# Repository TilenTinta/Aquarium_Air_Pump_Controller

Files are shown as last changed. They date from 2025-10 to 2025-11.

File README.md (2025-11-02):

# Aquarium_Air_Pump_Controller

Simple electronics for controlling aquarium air pump speed with some additional functions built around the WCH **CH32V003F4U6** MCU

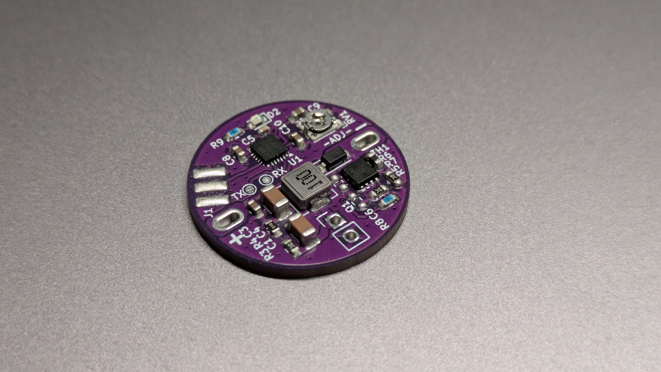
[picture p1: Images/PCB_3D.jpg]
Pump control pcb
  

---

## Table of Contents

- [Overview](#overview)
- [Features](#features)
  - [Hardware](#hardware)
  - [Software](#software)
- [Mounting](#mounting)
- [Flashing Firmware](#flashing-firmware)
- [Working device](#working-device)
  - [Working Principle](#working-principle)
- [Debugging](#debugging)
  - [LED Status Codes](#led-status-codes)

---

## Overview

This controller is a very compact solution for controling aquarium air pump speed. It is meant to be mounted on the back side of cheap chinese pumps that uses DC brushed motors like **PXYP370** and are powered from USB. By adjusting potenciometer on PCB you can tune pump speed and by that the amount of air provided in aquarium/filter. If you want to control this pump from external device like **ESP32** you can connect it over UART pads. This allow you to monitor and control the pump.

---

## Features

### Hardware

- **MCU:** WCH **CH32V003F4U6** with SWIO. 
- **Power:** Directly from 5V - USB.
- **Power regulation:** N-Channel MOSFET AP30N03DF.
- **Adjustment:** Duty cycle with potenciometer
- **Sensors:** Voltage IN, temperature.
- **Indicators/Controls:** Status LED and UART. 

### Software

- **Firmware:** C, developed in **MounRiver Studio IDE**. 
- **Updates:** **Custom bootloader** supports UART firmware updates. 

---

## Mounting

To mount controller on air pump you first need to remove silicon housing from the pump. Desolder both wires and bleed resistor from the motor contacts and clean them. Then solder the wires from USB cable to PCB. Correctly oriented pcb can be then soldered directly on motor contacts.

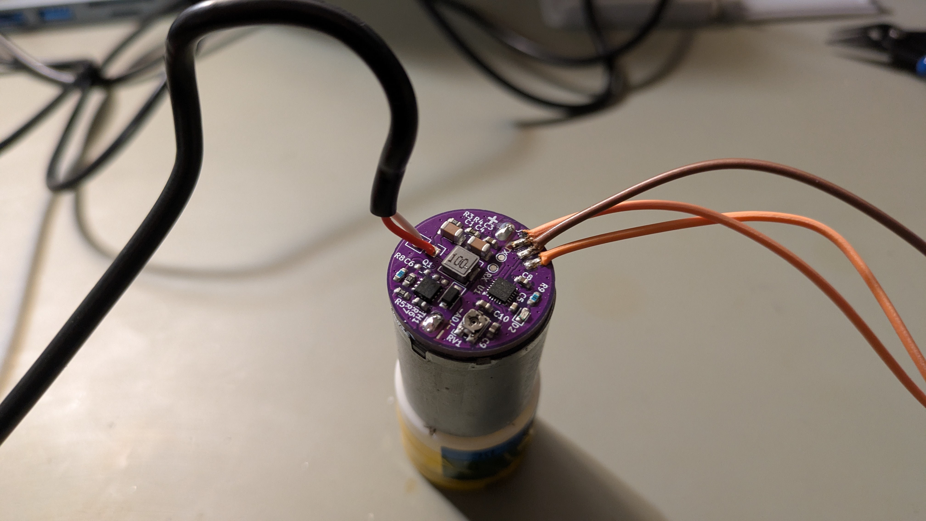
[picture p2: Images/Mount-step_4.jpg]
Pump control full
  

---

## Flashing Firmware

- Open the project in **MounRiver Studio IDE**, compile, and **upload** to the **CH32V003F4U6** MCU. 

> The board also includes a **custom bootloader** for **UART firmware updates** when supported by the desktop toolchain. 

---

## Working device

When USB cable is pluging the controler goes thrue start up routine. After that if everything is okay (input voltage, temperatue) it goes in running mode, otherwise it falls in error state which is indicated with **solid red light**.

### Working Principle

- **Sampling:** The system samples data at 50Hz*. In the first sample, the MCU collects raw measurements. In the next sample, these values are converted into real-world units (V, °C, %). This results in an effective sampling rate of 25Hz for the calculated values.
- **Control Logic:** Based on the collected values, the controller can either trigger an error or set a new duty cycle for the motor based on the potentiometer reading.
- **Error Conditions:**
    - **Over-temperature:** 80°C
    - **Under-voltage:** 3.5V
- **Duty Cycle:** The duty cycle can be set between 10% and 90%. Values below 10% are treated as 0%, and values above 90% are treated as 100%.
    - **Note:** This DC motors require a minimum of 3.0V - 3.5V to start.

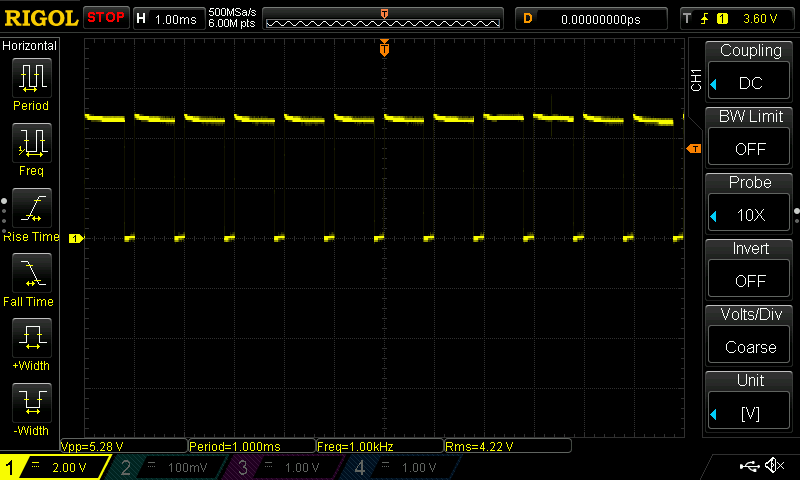
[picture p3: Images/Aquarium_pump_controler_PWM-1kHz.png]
Pump control PWM
 
---

## Debugging

### LED Status Codes  

| LED Pattern | Meaning |
|---|---|
| Blinking **red**  | Device initialization |
| Solid **red** | Device error |

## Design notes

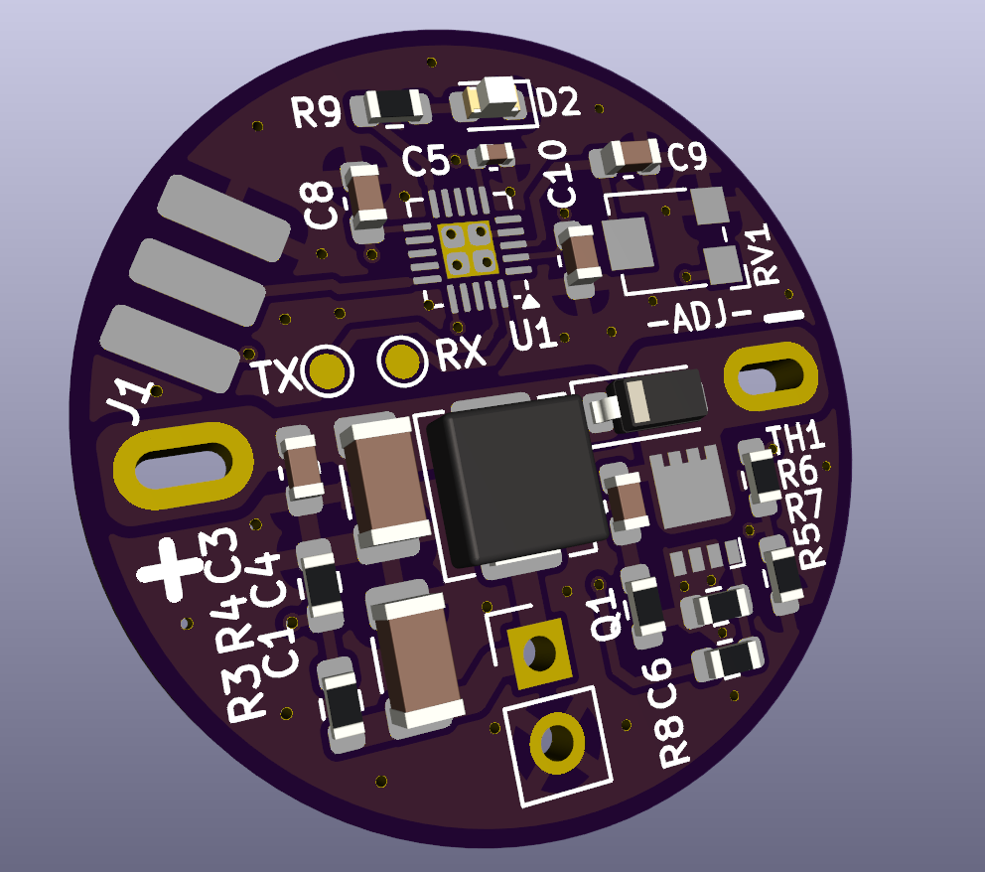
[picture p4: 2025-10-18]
Images/PCB_3D_render.png

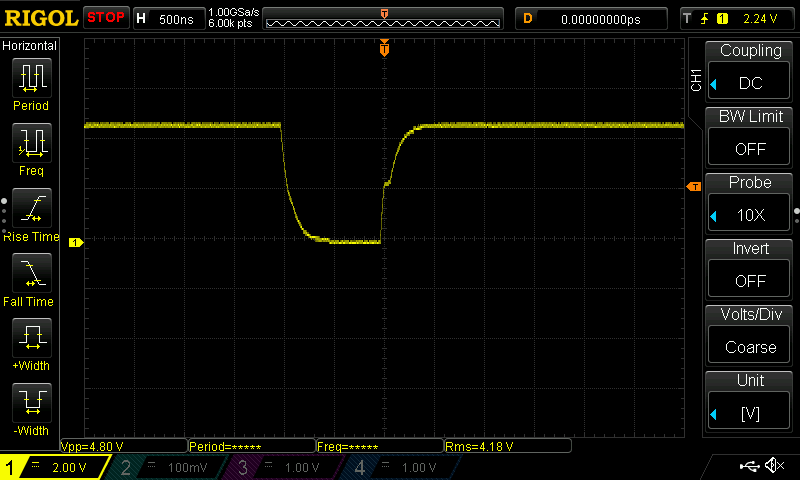
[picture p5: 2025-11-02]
Images/Aquarium_pump_controler_ON-OFF.png

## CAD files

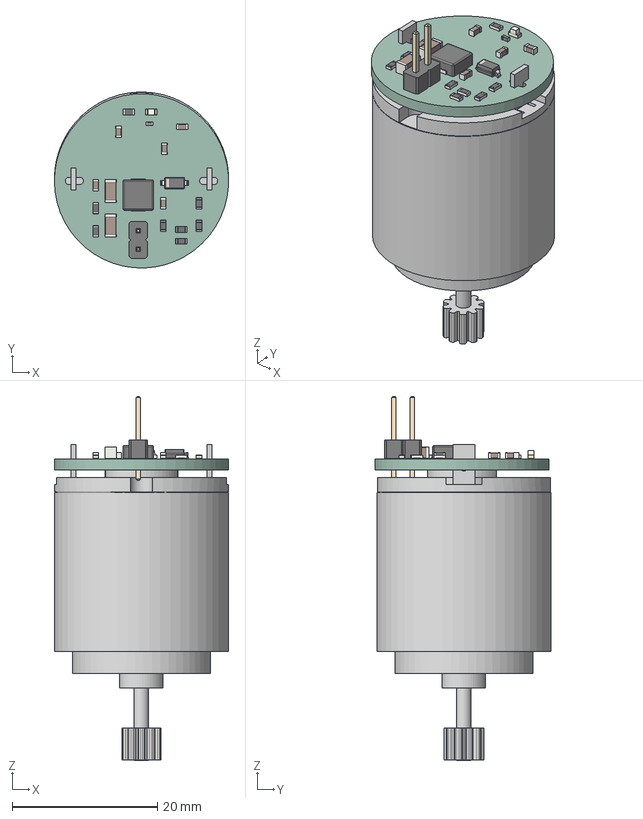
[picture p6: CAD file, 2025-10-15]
3D_Model/Assembly v1.step
24.0 x 24.2 x 50.1 mm
C_0603_1608Metric x 5
R_0603_1608Metric x 8
D_SOD-123
C_0402_1005Metric
C_1206_3216Metric x 2
L_APV_APH0420
PinHeader_1x02_P2.54mm_Vertical
LED_0603_1608Metric
Air_pump_controler_PCB
DC 12 v motor

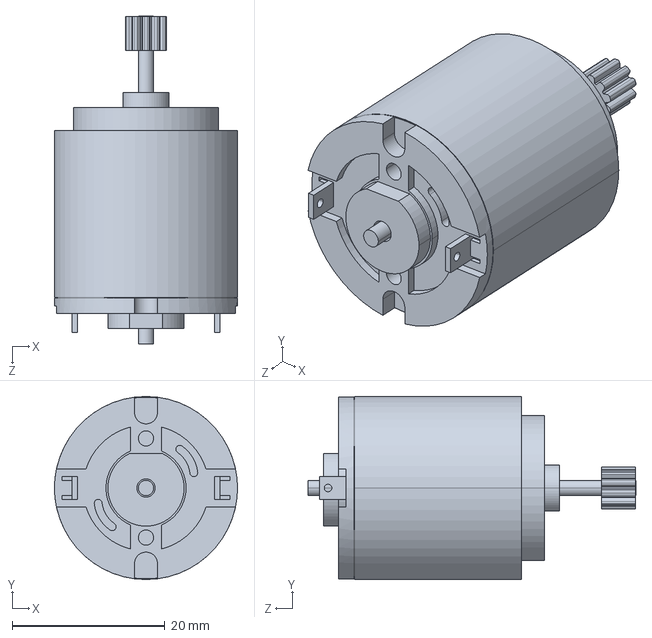
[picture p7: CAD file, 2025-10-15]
3D_Model/DC 12 v motor.STEP
24.0 x 24.0 x 43.0 mm

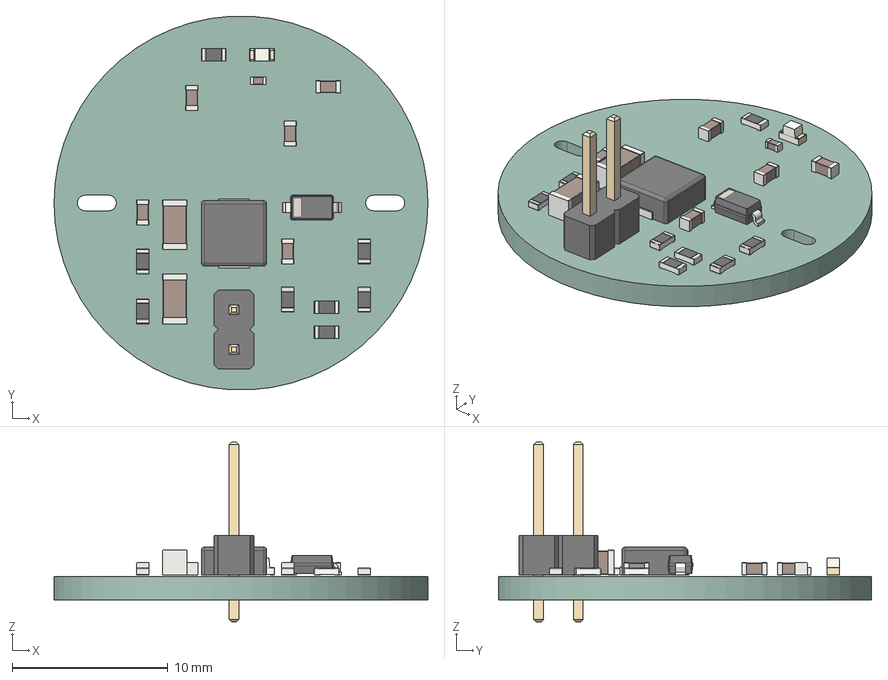
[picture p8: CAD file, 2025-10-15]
3D_Model/Air_pump_controler.step
24.0 x 24.0 x 11.5 mm
C_0603_1608Metric x 5
R_0603_1608Metric x 8
D_SOD-123
C_0402_1005Metric
C_1206_3216Metric x 2
L_APV_APH0420
PinHeader_1x02_P2.54mm_Vertical
LED_0603_1608Metric
Air_pump_controler_PCB

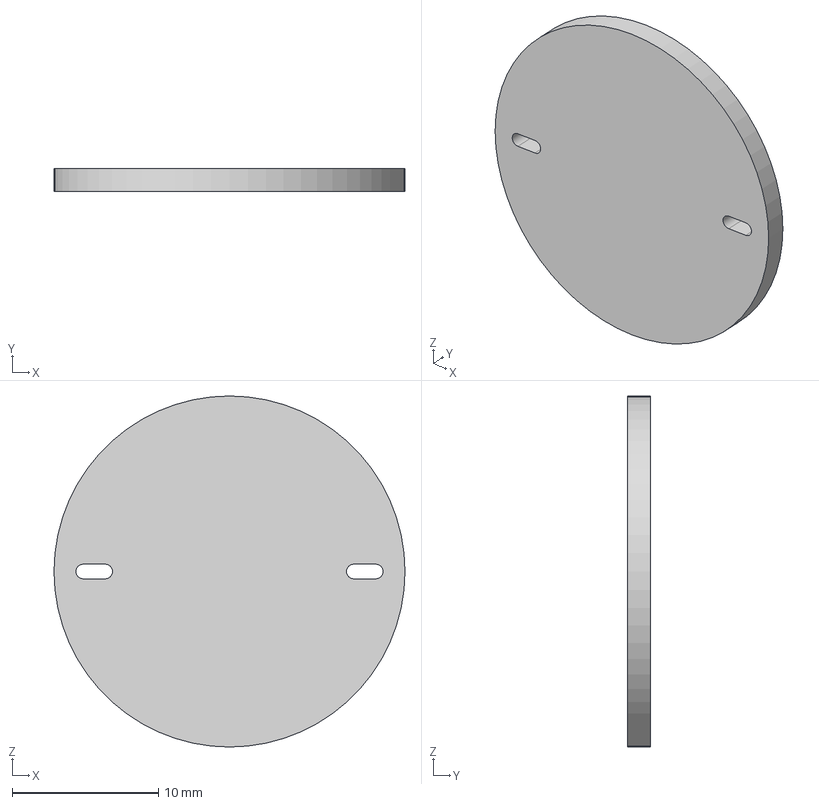
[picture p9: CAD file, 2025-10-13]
3D_Model/PCB_dummy v2.step
24.0 x 1.60 x 24.0 mm

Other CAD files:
3D_Model/PCB_dummy_v2.dxf

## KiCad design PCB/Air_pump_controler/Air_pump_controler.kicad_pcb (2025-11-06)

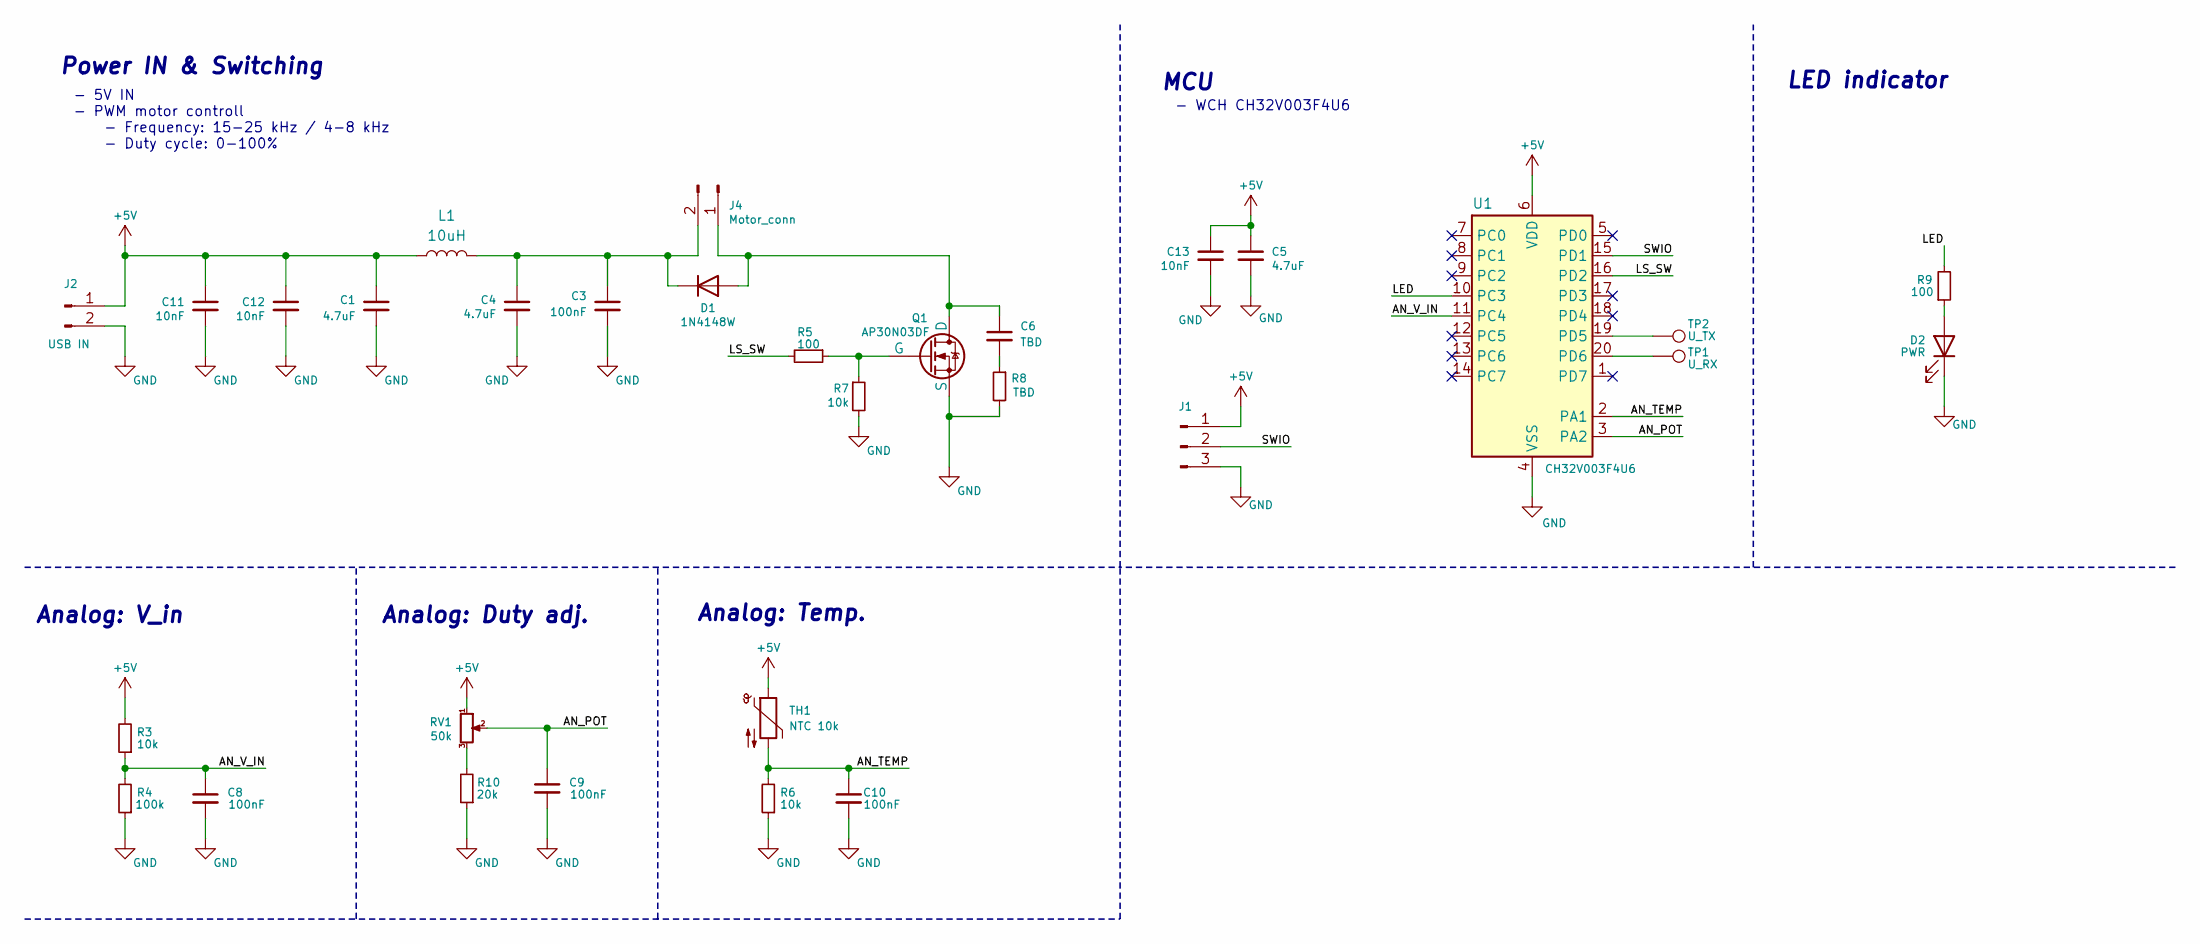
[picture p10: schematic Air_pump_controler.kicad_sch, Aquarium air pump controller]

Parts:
C1, C4: 4.7uF; C_1206_3216Metric
C3, C8, C9, C10: 100nF; C_0603_1608Metric
C5: 4.7uF; C_0402_1005Metric
C6: TBD; C_0603_1608Metric
C11, C12, C13: 10nF; C_0402_1005Metric
D1: 1N4148W; D_SOD-123
D2: PWR; LED_0603_1608Metric
J1: Conn_01x03_Pin; Samtec_UMPS-03-XX.X-X-V-S_1x03_P2.0mm_Socket
J2: USB IN; PinHeader_1x02_P2.54mm_Vertical
J4: Motor_conn
L1: 10uH; L_APV_APH0420
Q1: AP30N03DF
R3, R6, R7: 10k; R_0603_1608Metric
R4: 100k; R_0603_1608Metric
R5, R9: 100; R_0603_1608Metric
R8: TBD; R_0603_1608Metric
R10: 20k; R_0603_1608Metric
RV1: 50k; Potentiometer_Bourns_TC33X_Vertical
TH1: NTC 10k; R_0603_1608Metric
TP1: U_RX; TestPoint_Pad_D1.0mm
TP2: U_TX; TestPoint_Pad_D1.0mm
U1: CH32V003F4U6; QFN-20-1EP_3x3mm_P0.4mm_EP1.65x1.65mm

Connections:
+5V: C1.1, C5.1, C11.1, C12.1, C13.1, J1.1, J2.1, L1.1, R3.2, RV1.1, TH1.1, U1.6 (VDD)
/AN_POT: C9.1, RV1.2, U1.3 (PA2)
/AN_TEMP: C10.1, R6.2, TH1.2, U1.2 (PA1)
/AN_V_IN: C8.1, R3.1, R4.2, U1.11 (PC4)
/LED: R9.2, U1.10 (PC3)
/LS_SW: R5.2, U1.16 (PD2)
/SWIO: J1.2, U1.15 (PD1)
GND: C1.2, C3.2, C4.2, C5.2, C8.2, C9.2, C10.2, C11.2, C12.2, C13.2, D2.1 (K), J1.3, J2.2, Q1.1 (S), R4.1, R6.1, R7.2, R8.2, R10.1, U1.4 (VSS), U1.21 (VSS)
unnamed: C6.2, R8.1
unnamed: C6.1, D1.2 (A), J4.1, Q1.3 (D)
unnamed: C3.1, C4.1, D1.1 (K), J4.2, L1.2
unnamed: D2.2 (A), R9.1
unnamed: Q1.2 (G), R5.1, R7.1
unnamed: R10.2, RV1.3
unnamed 14: TP2.1, U1.19 (PD5); also elsewhere on the board
unnamed 15: TP1.1, U1.20 (PD6); also elsewhere on the board

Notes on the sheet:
Analog: Duty adj.
- 5V IN - PWM motor controll - Frequency: 15-25 kHz / 4-8 kHz - Duty cycle: 0-100%
LED indicator
Analog: Temp.
- WCH CH32V003F4U6
Analog: V_in
Power IN & Switching
MCU

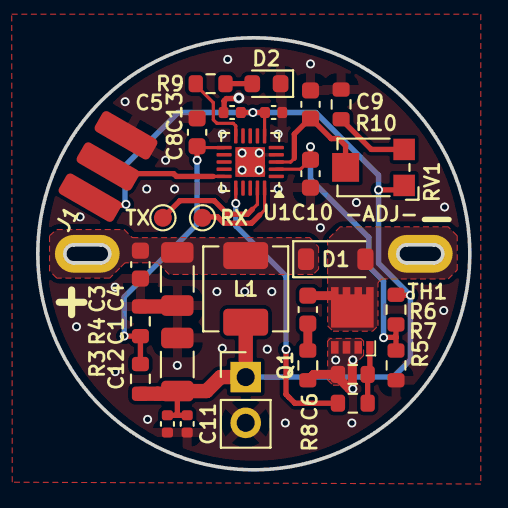
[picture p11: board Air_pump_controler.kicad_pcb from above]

Board: 2 copper layers, 24.0 x 24.0 mm, 31 parts (0 on the bottom side), 16 nets.

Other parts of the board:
RX: U_RX; TestPoint_Pad_D1.0mm
TX: U_TX; TestPoint_Pad_D1.0mm

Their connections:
unnamed 14: TX.1; also elsewhere on the board
unnamed 15: RX.1; also elsewhere on the board

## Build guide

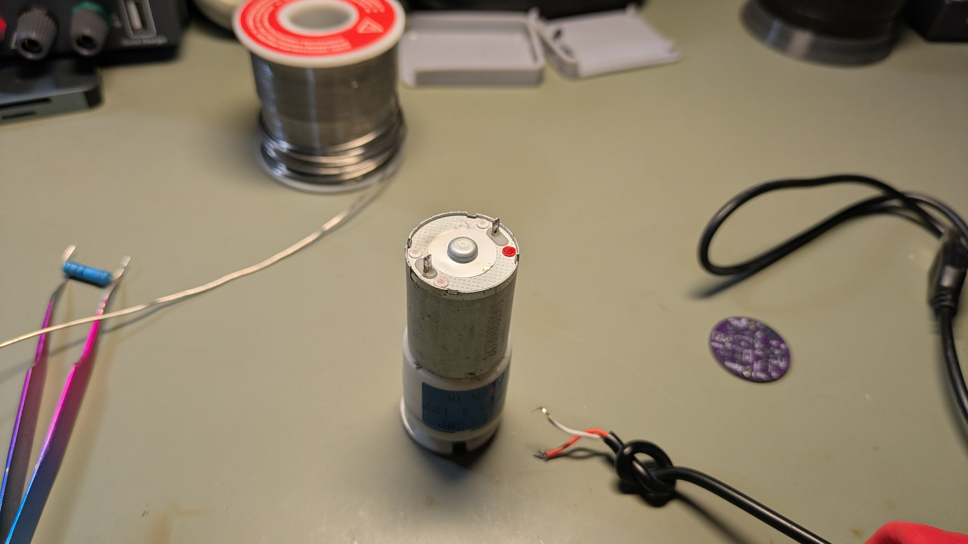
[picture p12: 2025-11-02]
Images/Mount-step_2.jpg

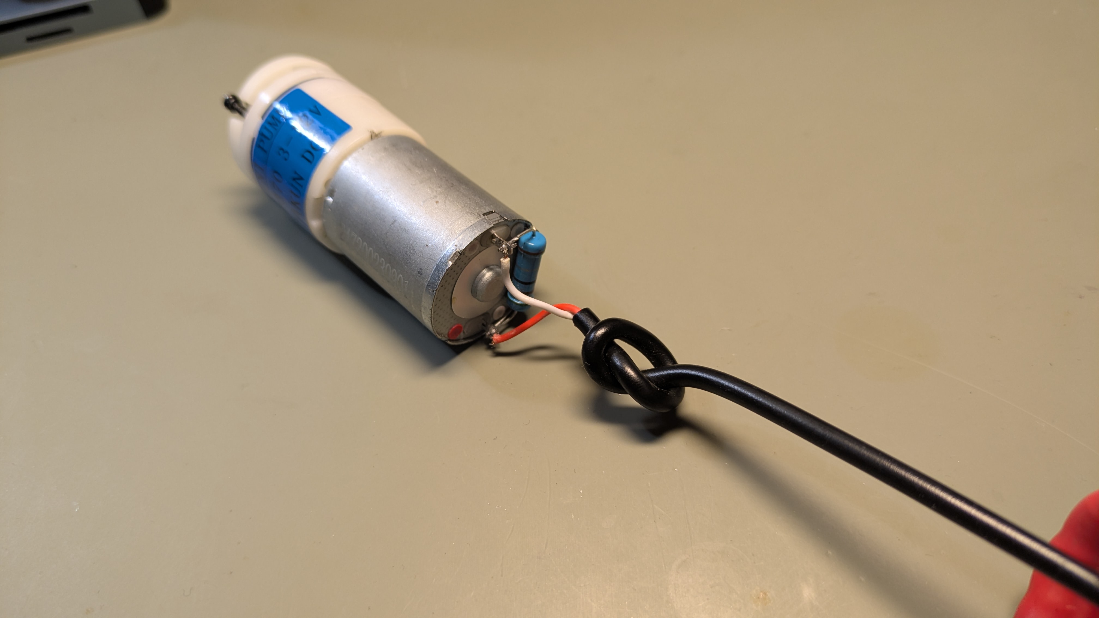
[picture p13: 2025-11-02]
Images/Mount-step_1.jpg

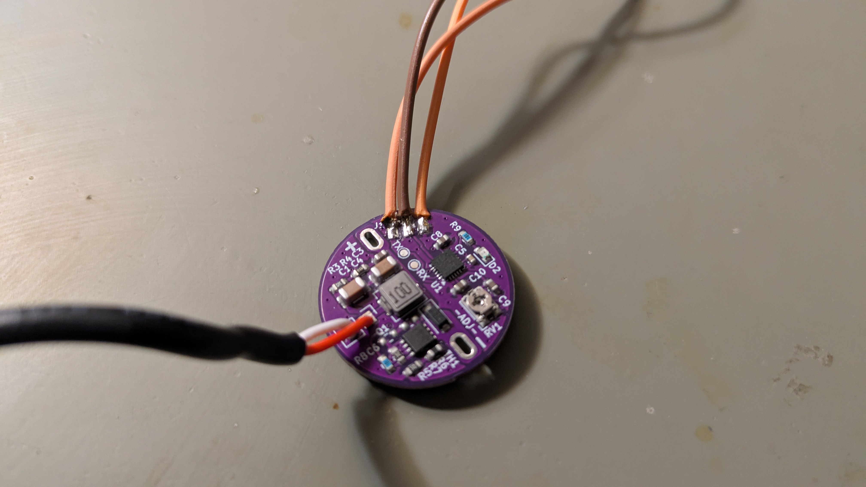
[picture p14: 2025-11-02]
Images/Mount-step_3.jpg

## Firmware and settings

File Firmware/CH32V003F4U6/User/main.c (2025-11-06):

/*****************************************************************
 * File Name          : main.c
 * Author             : Tinta T.
 * Version            : V1.0.0
 * Date               : 2025/10/16
 * Description        : Main file of Aquarium air pump controller
*****************************************************************/

/* Includes */
#include "debug.h"
#include "main.h"
#include "math.h"

/*###########################################################################################################################################################*/
/* Global define */
S_DEVICE sDevice;
S_ANALOG sAnalog;


/* Interrupts defines */
void USART1_IRQHandler(void) __attribute__((interrupt("WCH-Interrupt-fast")));
void TIM2_IRQHandler(void) __attribute__((interrupt("WCH-Interrupt-fast")));


/*###########################################################################################################################################################*/
/* Functions */
void USART1_Init(void);
void ControlPinout_Init(void);
void TIM_INT_Init(void);
void UartSendBuffer(uint8_t* buffer, uint16_t length);
void UART_buffer_clear(void);
void PWM1_Init(uint16_t arr, uint16_t psc, uint16_t pulse);
void PWM1_SetDuty(uint16_t pulse);
int16_t calculate_ntc_temperature(S_ANALOG *values);
uint16_t duty_to_timVal(uint8_t duty);
int8_t calculate_duty(S_ANALOG *values);


/*###########################################################################################################################################################*/
/* Global variables */



/*###########################################################################################################################################################*/

int main(void)
{
    // Device init //
    NVIC_PriorityGroupConfig(NVIC_PriorityGroup_1);         // Init USART
    SystemCoreClockUpdate();                                // Init all the clocks (used 48MHz HSI)
    Delay_Init();                                           // Enable delay
    ControlPinout_Init();                                   // Init the pinout
    TIM_INT_Init();                                         // Init the timer
    USART1_Init();                                          // Init USART
   
    // 1 kHz PWM: 
    //  - prescaler = 48-1 = 47 >> timer clock = 1 MHz, 
    //  - ARR = 1000-1 = 999 = period = 1000 counts = 1 kHz
    PWM1_Init(999, 47, 0);                                  // 0% duty (pulse = 0)
    // e.g.: PWM1_SetDuty(250);                             // 25% duty

    sDevice.bootDone = 0;                                   // Enable boot routine
    sDevice.flag_adc_read = 0;                              // Turn off ADC read
    sDevice.state = devBoot;                                // Set state of main state machine
    sDevice.analog_state = ADCread;                         // Set state of analog state machine
    sDevice.flag_analog_state = 0;                          // Flag used in IRQ to change mode of analog operation

    while(1)
    {
        /* MAIN STATE MACHINE */  
        switch (sDevice.state) 
        {

        // State: Device boot routine
        case devBoot:

            if (sDevice.bootDone == 1) 
            {
                sDevice.state = running;     // End of Boot sequence
                sDevice.analog_state = ADCread;
                break;
            }

            if (sDevice.flag_adc_read == 1)
            {
                sDevice.flag_adc_read = 0;  // Clear flag
                
                /* ANALOG STATE MACHINE */
                switch (sDevice.analog_state)
                {
                // State: Read analog values
                case ADCread:

                    // Read new ADC values and wait on DMA
                    ADC_SoftwareStartConvCmd(ADC1, ENABLE);
                    while (DMA_GetFlagStatus(DMA1_FLAG_TC1) == RESET);
                    DMA_ClearFlag(DMA1_FLAG_TC1);

                    sAnalog.analogVoltage = sAnalog.adcResults[0];
                    sAnalog.analogTemperature = sAnalog.adcResults[1];
                    sAnalog.analogPotenciometer = sAnalog.adcResults[2];

                    break;

                // State: Compute values
                case compute:

                    // Calculate raw values to messurements and set outputs
                    // --- Input voltage ---
                    sAnalog.voltage = (uint16_t)((float)sAnalog.analogVoltage / (float)(1024 - 1) * BASE_VOLTAGE);

                    // Undervoltage -> error
                    if (sAnalog.voltage < UNDER_VOLT)
                    {
                        sDevice.state = error;
                        break;
                    }

                    // --- Temperature ---
                    sAnalog.temperature = calculate_ntc_temperature(&sAnalog);

                    // Overtemperature -> error
                    if (sAnalog.temperature > OVER_TEMP)
                    {
                        sDevice.state = error;
                        break;
                    }

                    // --- Duty cycle ---
                    uint8_t percent = 0;
                    uint16_t percentSum = 0;
                    
                    // Shift values
                    for (int i = sizeof(sAnalog.potPercent) - 1; i > 0; i--)
                    {
                        sAnalog.potPercent[i] = sAnalog.potPercent[i-1];
                    }

                    // sAnalog.potPercent[0] = (uint8_t)((sAnalog.analogPotenciometer * 100) / 1024);       // PCB Rev.: 0.1
                    sAnalog.potPercent[0] = calculate_duty(&sAnalog);                                       // PCB Rev.: 0.2

                    // Average values
                    for (int i = 0; i < 10; i++)
                    {
                        percentSum += sAnalog.potPercent[i];
                    }

                    percent = (uint8_t)round(percentSum / sizeof(percentSum));

                    // Set PWM duty cycle
                    PWM1_SetDuty(duty_to_timVal(percent));

                    break;
                }
            }
            break;

        // State: Device is running normaly
        case running:
        
            if (sDevice.flag_adc_read == 1)
            {
                sDevice.flag_adc_read = 0;  // Clear flag
                
                /* ANALOG STATE MACHINE */
                switch (sDevice.analog_state)
                {
                // State: Read analog values
                case ADCread:

                    // Read new ADC values and wait on DMA
                    ADC_SoftwareStartConvCmd(ADC1, ENABLE);
                    while (DMA_GetFlagStatus(DMA1_FLAG_TC1) == RESET);
                    DMA_ClearFlag(DMA1_FLAG_TC1);

                    sAnalog.analogVoltage = sAnalog.adcResults[0];
                    sAnalog.analogTemperature = sAnalog.adcResults[1];
                    sAnalog.analogPotenciometer = sAnalog.adcResults[2];

                    break;

                // State: Compute values
                case compute:

                    // Calculate raw values to messurements and set outputs
                    // --- Input voltage ---
                    sAnalog.voltage = (uint16_t)((float)sAnalog.analogVoltage / (float)(1024 - 1) * BASE_VOLTAGE);

                    // Undervoltage -> error
                    if (sAnalog.voltage < UNDER_VOLT)
                    {
                        sDevice.state = error;
                        break;
                    }

                    // --- Temperature ---
                    sAnalog.temperature = calculate_ntc_temperature(&sAnalog);

                    // Overtemperature -> error
                    if (sAnalog.temperature > OVER_TEMP)
                    {
                        sDevice.state = error;
                        break;
                    }

                    // --- Duty cycle ---
                    uint8_t percent = 0;
                    uint16_t percentSum = 0;
                    
                    // Shift values
                    for (int i = sizeof(sAnalog.potPercent) - 1; i > 0; i--)
                    {
                        sAnalog.potPercent[i] = sAnalog.potPercent[i-1];
                    }
                    sAnalog.potPercent[0] = (uint8_t)((sAnalog.analogPotenciometer * 100) / 1024);

                    // Average values
                    for (int i = 0; i < 10; i++)
                    {
                        percentSum += sAnalog.potPercent[i];
                    }

                    percent = (uint8_t)round(percentSum / sizeof(percentSum));

                    // Set PWM duty cycle
                    PWM1_SetDuty(duty_to_timVal(percent));

                    break;
                }
            }

            break;

        // State: Error state
        case error:
                // Do nothing
                GPIO_WriteBit(GPIOC, LED_RED, Bit_SET);   // Turn ON led at error
            break;
        }
    }
}


/*###########################################################################################################################################################*/
/* Initialization */


/*********************************************************************
 * @fcn     GPIO_Init
 *
 * @brief   Initialises the GPIOs
 *
 * @return  none
 */
void ControlPinout_Init(void)
{
    ADC_InitTypeDef     ADC_InitStructure = {0};
    GPIO_InitTypeDef    GPIO_InitStructure = {0};
    DMA_InitTypeDef     DMA_InitStruct  = {0};

    RCC_APB2PeriphClockCmd(RCC_APB2Periph_GPIOA | RCC_APB2Periph_GPIOC | RCC_APB2Periph_GPIOD | RCC_APB2Periph_AFIO | RCC_APB2Periph_ADC1, ENABLE);
    RCC_AHBPeriphClockCmd(RCC_AHBPeriph_DMA1, ENABLE);

    // Set RED LED
    GPIO_InitStructure.GPIO_Pin = LED_RED;
    GPIO_InitStructure.GPIO_Speed = GPIO_Speed_30MHz;
    GPIO_InitStructure.GPIO_Mode = GPIO_Mode_Out_PP;
    GPIO_Init(GPIOC, &GPIO_InitStructure);

    // Set AN_TEMP, AN_POT and AN_V_IN
    GPIO_InitStructure.GPIO_Pin = AN_TEMP | AN_POT;
    GPIO_InitStructure.GPIO_Mode = GPIO_Mode_AIN;
    GPIO_Init(GPIOA, &GPIO_InitStructure);

    GPIO_InitStructure.GPIO_Pin = AN_V_IN;
    GPIO_Init(GPIOC, &GPIO_InitStructure);

    ADC_InitStructure.ADC_Mode = ADC_Mode_Independent;
    ADC_InitStructure.ADC_ScanConvMode = ENABLE;
    ADC_InitStructure.ADC_ContinuousConvMode = DISABLE;
    ADC_InitStructure.ADC_ExternalTrigConv = ADC_ExternalTrigConv_None;
    ADC_InitStructure.ADC_DataAlign = ADC_DataAlign_Right;
    ADC_InitStructure.ADC_NbrOfChannel = 3;
    ADC_Init(ADC1, &ADC_InitStructure);

    // Configure channel rank
    ADC_RegularChannelConfig(ADC1, ADC_CH_V_IN,  1, ADC_SampleTime_241Cycles);
    ADC_RegularChannelConfig(ADC1, ADC_CH_TEMP, 2, ADC_SampleTime_241Cycles);
    ADC_RegularChannelConfig(ADC1, ADC_CH_POT,  3, ADC_SampleTime_241Cycles);

    // DMA configuration
    DMA_DeInit(DMA1_Channel1);                                      // ADC1
    DMA_InitStruct.DMA_PeripheralBaseAddr = (uint32_t)&ADC1->RDATAR;
    DMA_InitStruct.DMA_MemoryBaseAddr     = (uint32_t)sAnalog.adcResults;
    DMA_InitStruct.DMA_DIR                = DMA_DIR_PeripheralSRC;  // peripheral to memory
    DMA_InitStruct.DMA_BufferSize         = 3;
    DMA_InitStruct.DMA_PeripheralInc      = DMA_PeripheralInc_Disable;
    DMA_InitStruct.DMA_MemoryInc          = DMA_MemoryInc_Enable;
    DMA_InitStruct.DMA_PeripheralDataSize = DMA_PeripheralDataSize_HalfWord;  // 16-bit
    DMA_InitStruct.DMA_MemoryDataSize     = DMA_MemoryDataSize_HalfWord;
    DMA_InitStruct.DMA_Mode               = DMA_Mode_Circular;          
    DMA_InitStruct.DMA_Priority           = DMA_Priority_High;
    DMA_InitStruct.DMA_M2M                = DMA_M2M_Disable;
    DMA_Init(DMA1_Channel1, &DMA_InitStruct);

    DMA_Cmd(DMA1_Channel1, ENABLE);

    // Enable ADC DMA
    ADC_DMACmd(ADC1, ENABLE);

    // Enable ADC
    ADC_Cmd(ADC1, ENABLE);

    // Calibrate ADC
    ADC_ResetCalibration(ADC1);
    while(ADC_GetResetCalibrationStatus(ADC1));
    ADC_StartCalibration(ADC1);
    while(ADC_GetCalibrationStatus(ADC1));

}



/*********************************************************************
 * @fcn     TIM_INT_Init
 *
 * @brief   Initialises Timer2: 50Hz / 20ms
 *
 * @return  none
 */
void TIM_INT_Init(void)
{
    // TIM1 - Advanced-control Timer (ADTM)
    // TIM2 - General-purpose Timer (GPTM)

    TIM_TimeBaseInitTypeDef TIMBase_InitStruct = {0};
    NVIC_InitTypeDef NVIC_InitStruct = {0};

    // Set values of registers
    uint16_t arr = 59999;
    uint16_t psc = 15; 

    RCC_APB1PeriphClockCmd(RCC_APB1Periph_TIM2, ENABLE);

    TIMBase_InitStruct.TIM_Period = arr;
    TIMBase_InitStruct.TIM_CounterMode = TIM_CounterMode_Up;
    TIMBase_InitStruct.TIM_Prescaler = psc;
    TIMBase_InitStruct.TIM_ClockDivision = TIM_CKD_DIV1;
    TIM_TimeBaseInit(TIM2, &TIMBase_InitStruct);

    TIM_ClearFlag(TIM2, TIM_FLAG_Update);
    NVIC_ClearPendingIRQ(TIM2_IRQn);
    TIM_ITConfig(TIM2, TIM_IT_Update, ENABLE);

    NVIC_InitStruct.NVIC_IRQChannel = TIM2_IRQn;
    NVIC_InitStruct.NVIC_IRQChannelPreemptionPriority = 1;
    NVIC_InitStruct.NVIC_IRQChannelSubPriority = 2;
    NVIC_InitStruct.NVIC_IRQChannelCmd = ENABLE;

    NVIC_Init(&NVIC_InitStruct);
    #ifdef DEBUG
        Delay_Ms(50);
    #endif
    TIM_Cmd(TIM2, ENABLE);
}



/*********************************************************************
 * @fcn     PWM1_Init
 *
 * @brief   Initialize Timer1 PWM
 *
 * @param   arr      ¡ª auto-reload value (period)
 * @param   psc      ¡ª prescaler
 * @param   pulse    ¡ª initial pulse width (CCR)
 *
 * @return  none
 */
void PWM1_Init(uint16_t arr, uint16_t psc, uint16_t pulse)
{
    GPIO_InitTypeDef GPIO_InitStructure = {0};
    TIM_TimeBaseInitTypeDef TIM_TimeBaseStructure = {0};
    TIM_OCInitTypeDef TIM_OCInitStructure = {0};

    RCC_APB2PeriphClockCmd(RCC_APB2Periph_GPIOD | RCC_APB2Periph_TIM1, ENABLE);

    GPIO_InitStructure.GPIO_Pin = LS_SW;
    GPIO_InitStructure.GPIO_Mode = GPIO_Mode_AF_PP;
    GPIO_InitStructure.GPIO_Speed = GPIO_Speed_50MHz;
    GPIO_Init(GPIOD, &GPIO_InitStructure);

    TIM_TimeBaseStructure.TIM_Period = arr;
    TIM_TimeBaseStructure.TIM_Prescaler = psc;
    TIM_TimeBaseStructure.TIM_ClockDivision = TIM_CKD_DIV1;
    TIM_TimeBaseStructure.TIM_CounterMode = TIM_CounterMode_Up;
    TIM_TimeBaseInit(TIM1, &TIM_TimeBaseStructure);

    TIM_OCInitStructure.TIM_OCMode = TIM_OCMode_PWM1;
    TIM_OCInitStructure.TIM_OutputState = TIM_OutputState_Enable;
    TIM_OCInitStructure.TIM_Pulse = pulse;
    TIM_OCInitStructure.TIM_OCPolarity = TIM_OCPolarity_High;

    // Use Timer1
    TIM_OC1Init(TIM1, &TIM_OCInitStructure);

    // Enable preload and PWM output enable
    TIM_OC1PreloadConfig(TIM1, TIM_OCPreload_Enable);
    TIM_ARRPreloadConfig(TIM1, ENABLE);

    // For TIM1 you need to enable main outputs
    TIM_CtrlPWMOutputs(TIM1, ENABLE);

    // Start timer
    TIM_Cmd(TIM1, ENABLE);
}



/*********************************************************************
 * @fcn      PWM1_SetDuty
 *
 * @brief   Change duty (pulse width) for LS_SW channel
 *          In tight corelation with timer frequency
 *
 * @param   pulse ¡ª new pulse value (0 .. arr)
 */
void PWM1_SetDuty(uint16_t pulse)
{
    TIM_SetCompare1(TIM1, pulse);
}



/*********************************************************************
 * @fcn      duty_to_timVal
 *
 * @brief   Calculate PWM timer value from percent
 *
 * @param   timer value
 */
uint16_t duty_to_timVal(uint8_t duty)
{
    uint16_t currentFreq = 1000;

    // Area of unvalid dutys
    if (duty < MIN_DUTY && duty != 0)
    {
        duty = 0;
    }
    else if (duty > MAX_DUTY && duty != 100)
    {
        duty = 100;
    }

    // Calculate timer value
    uint16_t value = (duty * currentFreq) / 100;

    if (value >= 1000) value = 999;
    if (value < 0) value = 0;

    return value;
}



/*********************************************************************
 * @fcn      USART1_Init
 *
 * @brief   Initializes the USART1 peripheral
 *
 * @return  none
 */
void USART1_Init(void)
{
    GPIO_InitTypeDef  GPIO_InitStructure = {0};
    USART_InitTypeDef USART_InitStructure = {0};
    NVIC_InitTypeDef NVIC_InitStructure = {0};

    RCC_APB2PeriphClockCmd(RCC_APB2Periph_GPIOD | RCC_APB2Periph_USART1 | RCC_APB2Periph_AFIO, ENABLE);

    // Set pin USART TX
    GPIO_InitStructure.GPIO_Pin = USART_RX;
    GPIO_InitStructure.GPIO_Speed = GPIO_Speed_30MHz;
    GPIO_InitStructure.GPIO_Mode = GPIO_Mode_AF_PP;
    GPIO_Init(GPIOD, &GPIO_InitStructure);

    // Set pin: USART RX
    GPIO_InitStructure.GPIO_Pin = USART_TX;
    GPIO_InitStructure.GPIO_Speed = GPIO_Speed_30MHz;
    GPIO_InitStructure.GPIO_Mode = GPIO_Mode_IN_FLOATING;
    GPIO_Init(GPIOD, &GPIO_InitStructure);

    // USART1 setup
    USART_InitStructure.USART_BaudRate = 115200;
    USART_InitStructure.USART_WordLength = USART_WordLength_8b;
    USART_InitStructure.USART_StopBits = USART_StopBits_1;
    USART_InitStructure.USART_Parity = USART_Parity_No;
    USART_InitStructure.USART_HardwareFlowControl = USART_HardwareFlowControl_None;
    USART_InitStructure.USART_Mode = USART_Mode_Tx | USART_Mode_Rx;
    USART_Init(USART1, &USART_InitStructure);

    // USART1 IRQ - RX
    USART_ITConfig(USART1, USART_IT_RXNE, ENABLE);
    NVIC_InitStructure.NVIC_IRQChannel = USART1_IRQn;
    NVIC_InitStructure.NVIC_IRQChannelPreemptionPriority = 1;
    NVIC_InitStructure.NVIC_IRQChannelSubPriority = 0;
    NVIC_InitStructure.NVIC_IRQChannelCmd = ENABLE;
    NVIC_Init(&NVIC_InitStructure);

    USART_Cmd(USART1, ENABLE);

}



/*********************************************************************
 * @fcn     USART1_IRQHandler
 *
 * @brief   Receive data over USART - USB comunication and saves
 *          them to the array in struct. Once the entire string is
 *          received (end marked with \n) the flag is set. This
 *          indicates that data can be decoded.
 *          Used only for parameters, setup...
 *
 * @return  none
 */
void USART1_IRQHandler(void)
{
    if(USART_GetITStatus(USART1, USART_IT_RXNE) != RESET)
    {
        // TODO: PWM value over UART and other commands

        // Clear RX flag (otherwise constantly triggered IRQ)
        USART_ClearITPendingBit(USART1, USART_IT_RXNE); 
    }
}



/*********************************************************************
 * @fn      TIM2_IRQHandler
 *
 * @brief   Timer interrupt - 50Hz/20ms
 *
 * @return  none
 */
void TIM2_IRQHandler(void)
{
    static uint8_t cntBlink = 0;
    static uint8_t cntBoot = 0;

    if (TIM_GetITStatus(TIM2, TIM_IT_Update) != RESET)
    {
        // Analog read channel switch //
        if (sDevice.state == devBoot || sDevice.state == running)
        {
            if (sDevice.flag_analog_state == 1)                     // Reset state/channel of ADC  
            {
                sDevice.flag_analog_state = 0;
                sDevice.analog_state = compute;                     // Change state/channel of ADC

                if (sDevice.state == devBoot)                       // Count cycles at boot
                {
                    cntBoot++;
                    if (cntBoot > 9) sDevice.bootDone = 1;          // End boot process
                } 
            } 
            else
            {
                sDevice.analog_state = ADCread;                     // Change state/channel of ADC
                sDevice.flag_analog_state = 1;
            }
            sDevice.flag_adc_read = 1;                              // Trigger ADC reading and computing
        }

        // Boot led //
        if (sDevice.bootDone == 0)
        {
            cntBlink++;                                             // Timer counters

            // Blink LED (twice per second)
            if (cntBlink >= 6)
            {
                GPIO_WriteBit(GPIOC, LED_RED, (BitAction)!GPIO_ReadOutputDataBit(GPIOC, LED_RED));
                cntBlink = 0;
            }
        }
        else
        {
            GPIO_WriteBit(GPIOC, LED_RED, Bit_RESET);               // Turn OFF led after boot
        }

        TIM_ClearITPendingBit(TIM2, TIM_IT_Update);                 // Clear flag            
    }
}
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

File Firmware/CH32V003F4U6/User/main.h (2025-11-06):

/***************************************************************************
 * File Name          : main.h
 * Author             : Tinta T.
 * Version            : V1.0.0
 * Date               : 2025/10/16
 * Description        : Main header file of Aquarium air pump controller
***************************************************************************/

#ifndef USER_MAIN_H_
#define USER_MAIN_H_

/* Includes */
#include <stdio.h>
#include <stdint.h>
#include <string.h>

/*###########################################################################################################################################################*/
/* Defines */

// Device constants
#define DEVICE_NAME    "Pump control"   // Name of the device
#define SW_VER              1           // Software version (used in UART packets)
#define SW_DATE        "October 2025"   // Date of software

#define OVER_TEMP           80          // Over temperature protection
#define BASE_VOLTAGE        500         // Expected voltage on the input
#define UNDER_VOLT          350         // Under voltage protection (3.5V)
#define MIN_DUTY            10          // Minimum value of duty cycle (lower is 0)
#define MAX_DUTY            90          // Maximum value of duty cycle (higher is 100)
#define V_IN_R1             10000       // Voltage divider (input voltage) R1 
#define V_IN_R2             100000      // Voltage divider (input voltage) R2 
#define DUTY_VREF           5           // Duty cycle ideal reference voltage
//#define DUTY_POT          20000       // Potenciometer (duty cycle), PCB Rev.: 0.1
#define DUTY_POT            50000       // Potenciometer (duty cycle), PCB Rev.: 0.2
#define DUTY_R              1800        // Resistor R2 (duty cycle), PCB Rev.: 0.2
#define TEMP_BETA           39500       // Voltage divider (temperature) NTC Beta value
#define TEMP_R0             10000       // R_0 value of NTC
#define TEMP_R              10000       // Voltage divider (temperature) R2 
#define TEMP_T_0            29815       // T_0 - reference temperature 25C / 298.15K

// Pinout
#define LED_RED             GPIO_Pin_3  // PC3: Pin of red LED
#define LS_SW               GPIO_Pin_2  // PD2: Low side switching mosfet
#define USART_TX            GPIO_Pin_5  // PD5: UART TX
#define USART_RX            GPIO_Pin_6  // PD6: UART RX
#define AN_V_IN             GPIO_Pin_4  // PC4: Analog read - USB voltage
#define ADC_CH_V_IN         ADC_Channel_2   // ADC Channel of PC4
#define AN_TEMP             GPIO_Pin_1  // PA1: Analog read - Temperature
#define ADC_CH_TEMP         ADC_Channel_1   // ADC Channel of PA1
#define AN_POT              GPIO_Pin_2  // PA2: Analog read - Potenciomeret voltage
#define ADC_CH_POT          ADC_Channel_0   // ADC Channel of PA2

/*###########################################################################################################################################################*/
/* Structs - marked with s at the beginning*/

typedef struct {
    uint8_t     bootDone;               // Flag: signal end of device initialization
    uint8_t     state;                  // Main state machine variable   
    uint8_t     analog_state;           // Analog read state machine variable  
    uint8_t     flag_analog_state;      // Flag used in IRQ for state monitoring
    uint8_t     flag_adc_read;          // Flag: read ADC value from current channel
    uint8_t     flag_overtemp;          // Flag: overtemperature protection
    uint8_t     flag_undervoltage;      // Flag: undervoltage protection
    uint16_t    duty;                   // Value if current duty cycle
} S_DEVICE;

typedef struct {            
    uint16_t    adcResults[3];          // buffer for ADC DMA results
    uint16_t    analogVoltage;          // Raw analog value of input voltage (10bit)
    uint16_t    analogTemperature;      // Raw analog value of temperature (10bit)
    uint16_t    analogPotenciometer;    // Raw analog value of potenciometer (10bit)
    uint16_t    voltage;                // Current value of input voltage
    uint16_t    temperature;            // Current value of temprature
    uint16_t    potVal;                 // Current value of potenciometer
    uint16_t    potPercent[10];         // Array of measurements from potenciometers
} S_ANALOG;


// Enumerate of states used in main state machine
enum eMainStates {
    devBoot,
    running,
    error
};

// Enumerate of states used in analog read state machine
enum eAnalogStates {
    ADCread,
    compute
};


#endif /* USER_MAIN_H_ */

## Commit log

2025-10-13 First commit
    PCB started, PCB edge
    [Air_pump_controler.kicad_pcb, Air_pump_controler.kicad_sch, PCB_dummy v2.step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]
2025-10-14 Update
    PCB shematic and layout done rev.:0.1
    [Air_pump_controler.kicad_pcb, Air_pump_controler.kicad_sch]
2025-10-15 Finished PCB
    [Air_pump_controler-B_Cu.gbr, Air_pump_controler-B_Mask.gbr, Air_pump_controler-B_Paste.gbr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]
2025-10-19 Update
    software
    [Air_pump_controler.kicad_sch]
2025-10-23 Update
    first FW complete, not tested on PCB
2025-11-02 Update
    pcb assembled, firmware works, added images
2025-11-05 Update
    modified potenciometer to voltage divider
    [Air_pump_controler.kicad_pcb, Air_pump_controler.kicad_sch]
2025-11-05 Update
    updated shematic and layout sheets and SW
    [Air_pump_controler.kicad_pcb, Air_pump_controler.kicad_sch]
2025-11-06 Update
    input voltage compensation for duty cycle
    [Air_pump_controler.kicad_sch]
2025-11-06 Update
    changed potenciometer voltage divider, added filter cap
    [Air_pump_controler.kicad_pcb, Air_pump_controler.kicad_sch]
2025-11-06 Update
    added filter cap on input
    [Air_pump_controler.kicad_sch]
2025-11-06 Update
    new gerbers
    [Air_pump_controler-B_Cu.gbr, Air_pump_controler-B_Mask.gbr, Air_pump_controler-B_Paste.gbr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]
